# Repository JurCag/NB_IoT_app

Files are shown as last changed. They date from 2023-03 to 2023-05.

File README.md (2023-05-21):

# NB-IoT Application

Table of contents:
- [Introduction](#introduction)
- [System Architecture](#system-architecture)
- [Web Application](#web-application)
- [Firmware and Hardware](#firmware-and-hardware)
    - [Communication overview](#communication-overview)
    - [Development tools](#development-tools)
  - [NB-IoT Concentrator](#nb-iot-concentrator)
    - [Firmware](#firmware)
    - [Hardware](#hardware)
  - [Sensor Boards](#sensor-boards)
    - [Firmware](#firmware)
    - [Hardware](#hardware)
 
#### Introduction:
Project showcases the application of NB-IoT technology for uploading data to the cloud. 
Hardware involves an NB-IoT concentrator and 6 sensor nodes equipped with different sensors, specifically designed to measure parameters of a [photobioreactor](https://en.wikipedia.org/wiki/Photobioreactor).<br />
Simple concept of the application including PBR is available [here](https://github.com/JurCag/NB_IoT_app/blob/master/images/photobioreactor.svg).

#### System Architecture:
<div align="center">
System Architecture
</div>

## Web Application

#### Description:
Simple web application for sensor data visualization and control of NB-IoT concentrator.

#### External libraries:
- AWS SDK: to access AWS services
- JSZip: to manipulate ZIP files
- Highcharts: data visualization

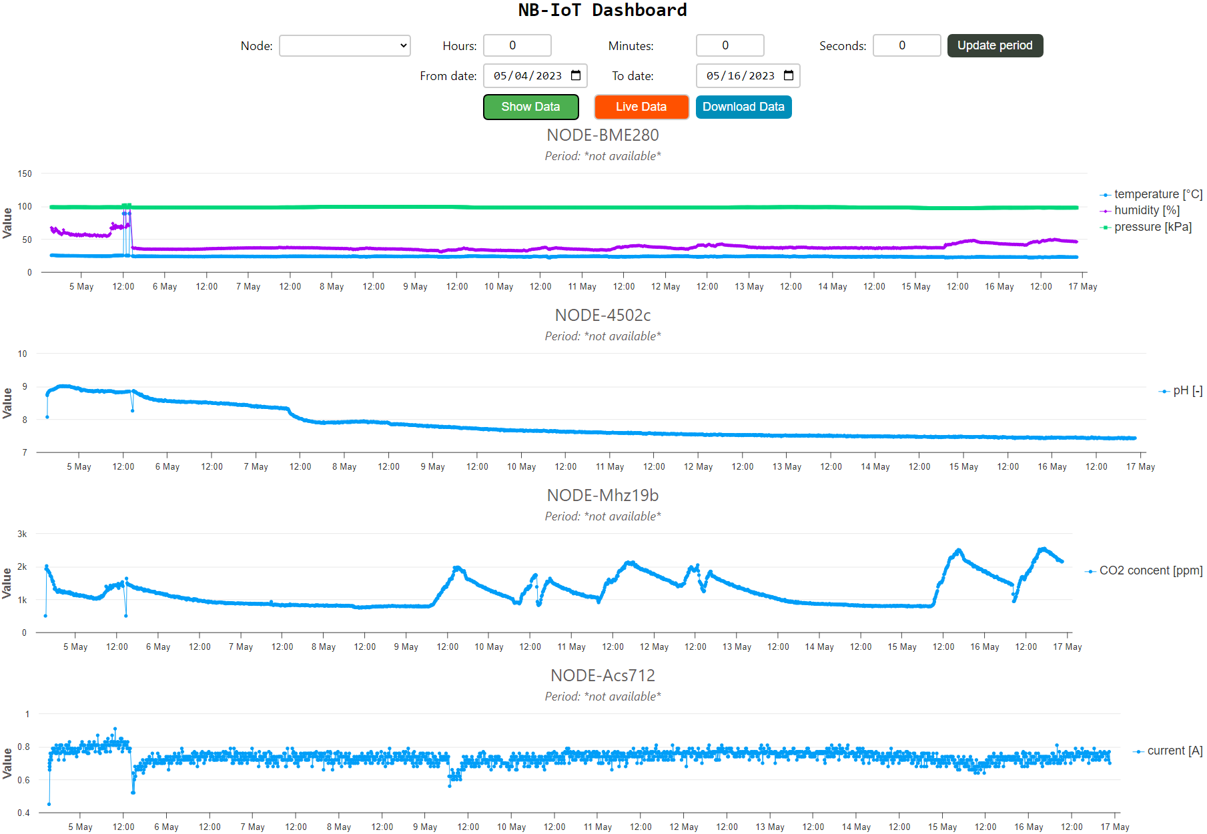
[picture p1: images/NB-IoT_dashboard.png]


## Firmware and Hardware

#### Communication overview:
The application uses [MQTT](https://mqtt.org/) protocol to communicate with broker within the AWS IoT Core. MQTT topics and structure of JSON payloads sent in the messages is shown below.
1) The concentrator provisions new nodes into the BLE mesh network. Nodes provide their descriptors.
2) The user requests the node measurement period by publishing a message to the topic: **BG96_demoThing/mmtPeriods/command**.
3) The concentrator responds with the current measurement period of that node to the topic: **BG96_demoThing/mmtPeriods/response**.
4) The user can change the node measurement period (e.g. 10 minutes).
5) The concentrator confirms the change by repeating the message.
6) The concentrator stores the measurement period value into the NVS (Non-Volatile Storage) memory.
7) When the counter reaches the specified period, the concentrator requests data from the sensor node over the BLE mesh.
8) The sensor node sends measured data.
9) The concentrator uploads the sensory data to AWS on the MQTT topic: **BG96_demoThing/sensors/\<nodeName\>**.
  
<div align="center">
  System Architecture
</div>

#### Development tools:
- VSCode + [PlatformIO](https://platformio.org/)
- Framework: ESP-IDF (within platformio project, no need to install separately)

### NB-IoT Concentrator 
#### Firmware:
- The concentrator, acting as a master device, collects measurement data from sensor nodes and uploads it to the AWS IoT Core.
- The concentrator also establishes a local BLE mesh network and provisions other nodes into the network.
- BLE mesh models implemented by concentrator:
  - Configuration Server
  - Configuration Client
  - Sensor Client 

#### Hardware:
[Custom PCB board](https://github.com/JurCag/NB_IoT_app/tree/master/NB-IoT_PCB_rev_1_1) with ESP32-C3 controller and Quectel BG96 module.

| Component | Link  |
| :---  |:---:|
| **MCU** | [ESP32-C3](https://www.espressif.com/en/products/socs/esp32-c3) |
| **NB-IoT module** | [Quectel BG96](https://www.quectel.com/product/lpwa-bg96-cat-m1-nb1-egprs) |
| **NB-IoT module board** | [LTE IoT 2 Click](https://www.mikroe.com/lte-iot-2-click) |
| **NB-IoT concentrator** | [NB-IoT_PCB_rev_1_1](https://github.com/JurCag/NB_IoT_app/tree/master/NB-IoT_PCB_rev_1_1) |

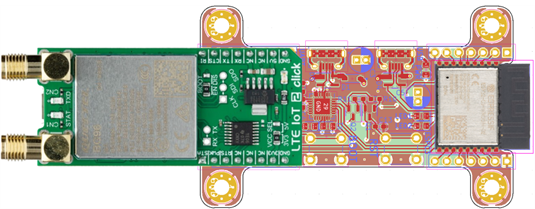
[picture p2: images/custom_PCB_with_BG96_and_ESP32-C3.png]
System Architecture


### Sensor boards
#### Firmware:
- Each sensor node incorporates the same BLE mesh models.
- BLE mesh models implemented by sensor nodes:
  - Configuration Server
  - Sensor Server 
  - Sensor Setup Server 
- The drivers are specific to the corresponding sensor they are equipped with.

#### Hardware:
 - **Control board:<br />**
 Each sensor node has the same control board: [ESP32-C3-DevKitC-02](https://docs.espressif.com/projects/esp-idf/en/latest/esp32c3/hw-reference/esp32c3/user-guide-devkitc-02.html)



 - **Sensors:<br />**

| Physical quantities | Sensor |  Connection | 
| :---: |:---:|:---:|
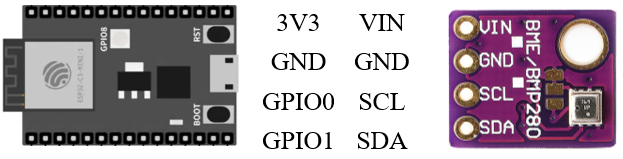
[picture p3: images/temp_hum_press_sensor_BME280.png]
| temperature,<br /> humidity,<br /> pressure | BME280 ||
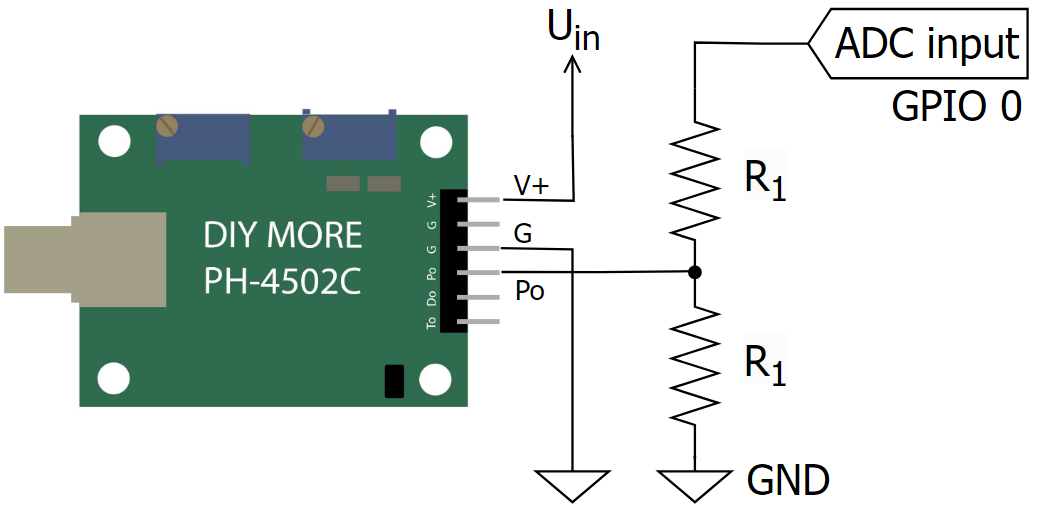
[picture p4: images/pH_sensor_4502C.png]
| pH | PH4502C ||
| CO_2 concentration | MHZ19B ||
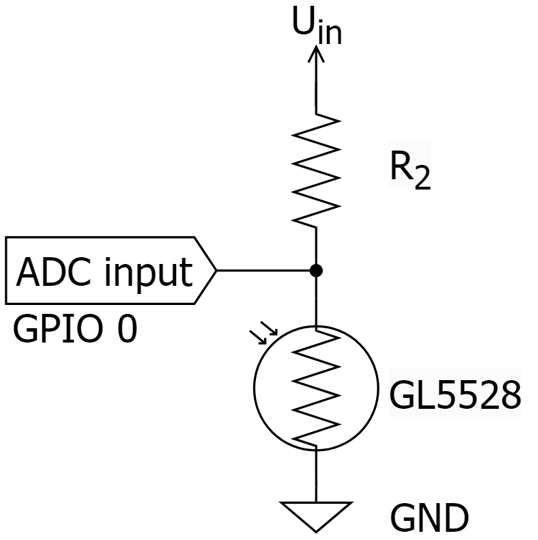
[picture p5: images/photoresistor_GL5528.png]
| light intensity | GL5528 ||
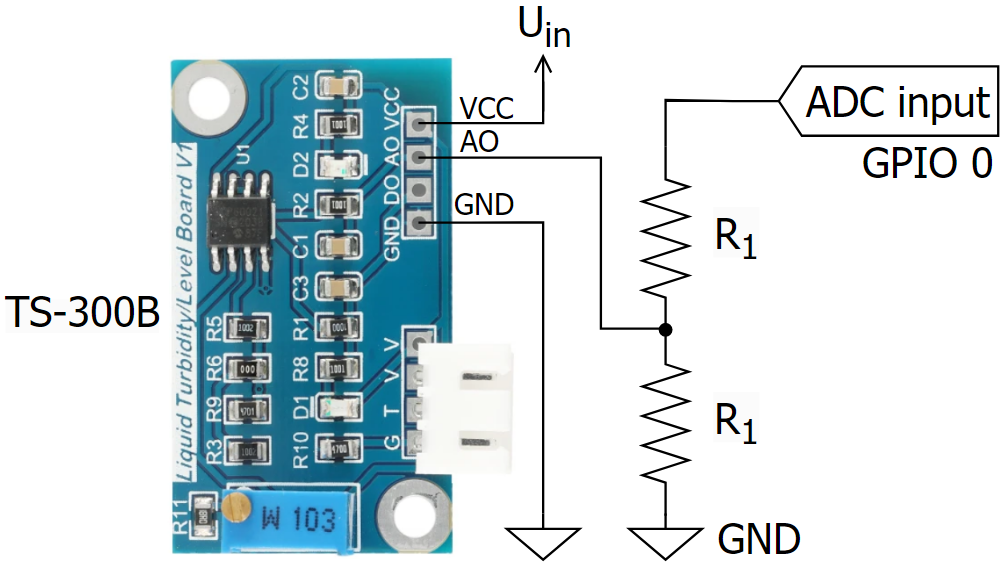
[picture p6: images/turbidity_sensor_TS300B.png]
| turbidity | TS300B ||
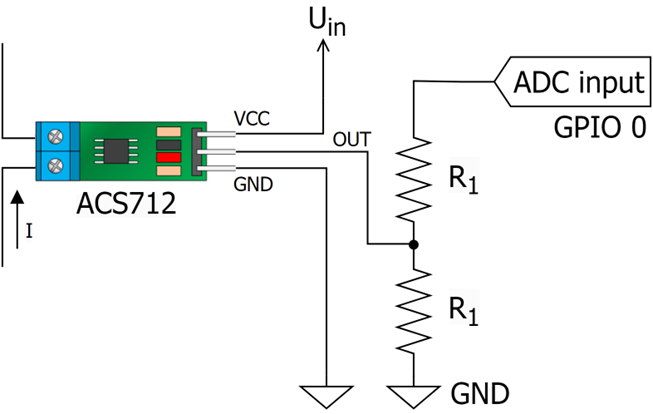
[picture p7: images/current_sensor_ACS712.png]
| electric current | ACS712 ||

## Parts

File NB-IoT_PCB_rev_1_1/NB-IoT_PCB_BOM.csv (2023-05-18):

Id | Designator | Package | Quantity | Designation | Supplier and ref
1 | D3 | D_MiniMELF | 1 | BZV55C15 | https://www.tme.eu/cz/details/bzv55c15-cdi/zenerovy-diody-smd/cdil/bzv55c15/
2 | D4,D5 | SOT-143_Handsoldering | 2 | PRTR5V0U2X | https://www.tme.eu/cz/sk/details/prtr5v0u2x.215/bezpecnostne-diody-rebriky/nexperia/
3 | J2 | USB_Micro-B_Amphenol_10118194_Horizontal | 1 | USB_UART | https://cz.mouser.com/ProductDetail/Hirose-Connector/ZX62D-B-5PA830?qs=1Nn7v2rJFSJs6IftS%252BmZAw%3D%3D
4 | C5,C3 | CP_Radial_D5.0mm_P2.00mm | 2 | 100uF/10V
5 | LED2 | D_0805_2012Metric_Pad1.15x1.40mm_HandSolder | 1 | USER LED 2
6 | D8 | D_0805_2012Metric_Pad1.15x1.40mm_HandSolder | 1 | PWR LED
7 | Q1,Q2 | SOT-23 | 2 | BC817
8 | R11,R10,R9 | R_0603_1608Metric_Pad0.98x0.95mm_HandSolder | 3 | 10k(1%)
9 | J3,J6 | PinSocket_1x08_P2.54mm_Vertical | 2 | Conn_01x08_Female
10 | D7 | D_0805_2012Metric_Pad1.15x1.40mm_HandSolder | 1 | RX LED
11 | C13,C14,C2,C8,C10,C11 | C_0603_1608Metric_Pad1.08x0.95mm_HandSolder | 6 | 100nF/50V
12 | R12,R8,R3,R7 | R_0603_1608Metric_Pad0.98x0.95mm_HandSolder | 4 | 1k
13 | U1 | QFN-28-1EP_5x5mm_P0.5mm_EP3.35x3.35mm | 1 | CP2102N-Axx-xQFN28
14 | LED1 | D_0805_2012Metric_Pad1.15x1.40mm_HandSolder | 1 | USER LED 1
15 | J4,J5 | PinSocket_1x05_P2.54mm_Vertical | 2 | Conn_01x05
16 | R1 | R_0603_1608Metric_Pad0.98x0.95mm_HandSolder | 1 | 22.1k
17 | D6 | D_0805_2012Metric_Pad1.15x1.40mm_HandSolder | 1 | TX LED
18 | D1,D2 | SOD3715X145N | 2 | 1N5819HW | https://www.tme.eu/cz/sk/details/1n5819hw-7-f/diody-schottky-smd/diodes-incorporated/
19 | RST1,BOOT1 | SW_PUSH_6mm_H5mm | 2 | SW_Push
20 | U3 | ESP32-C3-WROOM-02 | 1 | ESP32-C3-WROOM-02
21 | C4 | C_0603_1608Metric_Pad1.08x0.95mm_HandSolder | 1 | 1uF/50V
22 | J1 | USB_Micro-B_Amphenol_10118194_Horizontal | 1 | USB | https://cz.mouser.com/ProductDetail/Hirose-Connector/ZX62D-B-5PA830?qs=1Nn7v2rJFSJs6IftS%252BmZAw%3D%3D
23 | R2 | R_0603_1608Metric_Pad0.98x0.95mm_HandSolder | 1 | 47.5k
24 | U2 | SOT-223-3_TabPin2 | 1 | LD1117S33TR_SOT223 | https://www.tme.eu/cz/details/ld1117s33ctr/stabilizatory-napeti-neregulovane-ldo/stmicroelectronics/
25 | F1 | FP_for_SD050-16_POLY_FUSE | 1 | SD050-16_Poly_Fuse | http://www.tme.eu/cz/details/sd050-16/polymerove-pojistky-smd/ece/
26 | R5,R4 | R_0603_1608Metric_Pad0.98x0.95mm_HandSolder | 2 | 0(1%)
27 | R13,R14 | R_0603_1608Metric_Pad0.98x0.95mm_HandSolder | 2 | 1k(NC)
28 | C9 | C_1206_3216Metric_Pad1.33x1.80mm_HandSolder | 1 | 10uF/50V
29 | R6 | R_0603_1608Metric_Pad0.98x0.95mm_HandSolder | 1 | 0(1%)(NC)
30 | C6 | C_1206_3216Metric_Pad1.33x1.80mm_HandSolder | 1 | 1uF/50V
31 | C1 | C_1210_3225Metric_Pad1.33x2.70mm_HandSolder | 1 | 4.7uF
32 | C12,C7 | C_0805_2012Metric_Pad1.18x1.45mm_HandSolder | 2 | 10uF/50V

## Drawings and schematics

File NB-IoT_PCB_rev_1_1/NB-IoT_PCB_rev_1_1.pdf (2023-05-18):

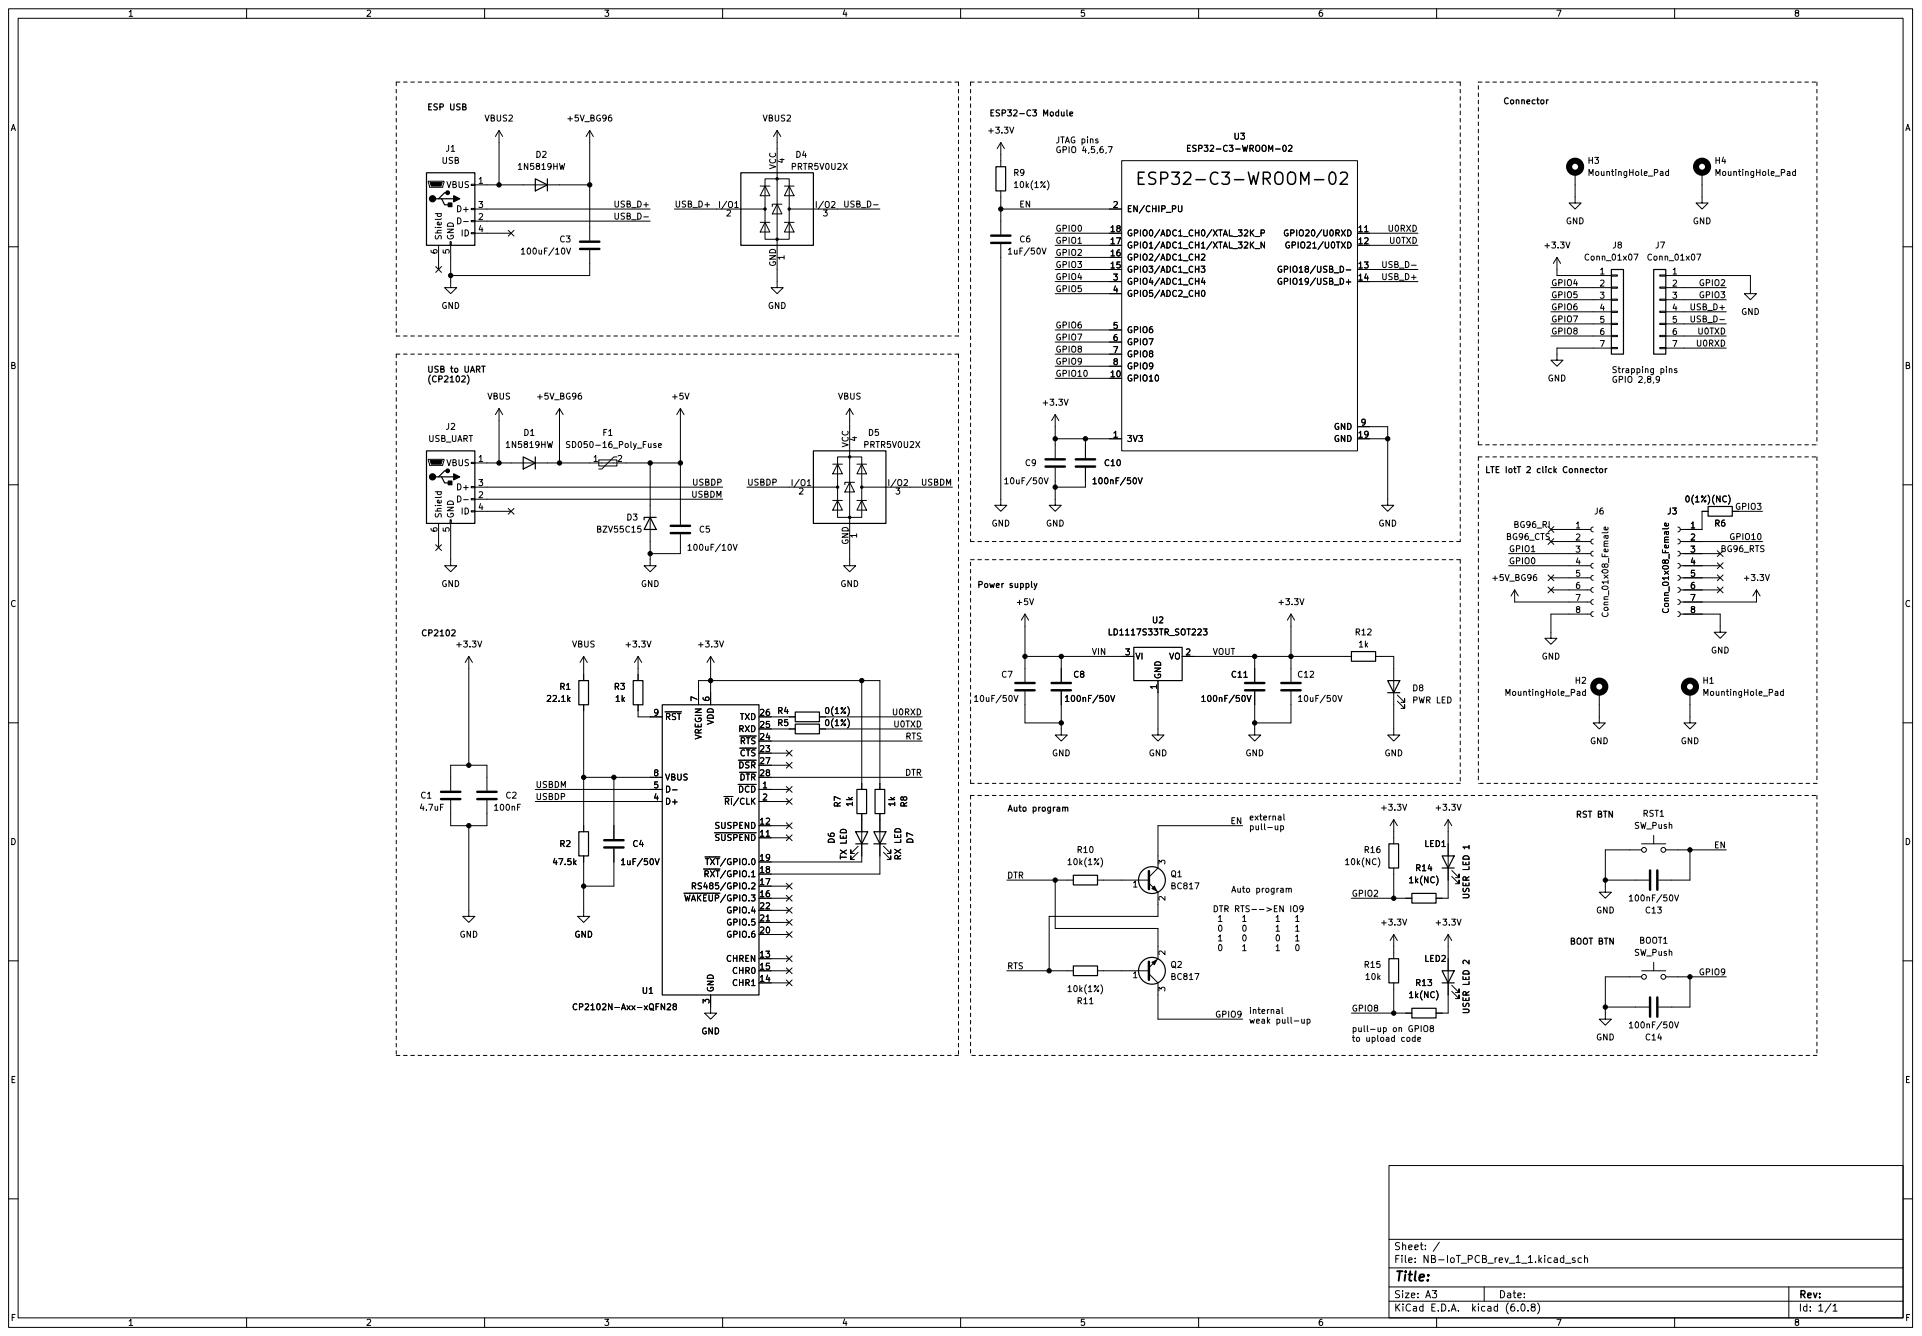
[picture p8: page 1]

JTAG pins GPIO 4,5,6,7 ESP32-C3 Module

internal weak pull-up

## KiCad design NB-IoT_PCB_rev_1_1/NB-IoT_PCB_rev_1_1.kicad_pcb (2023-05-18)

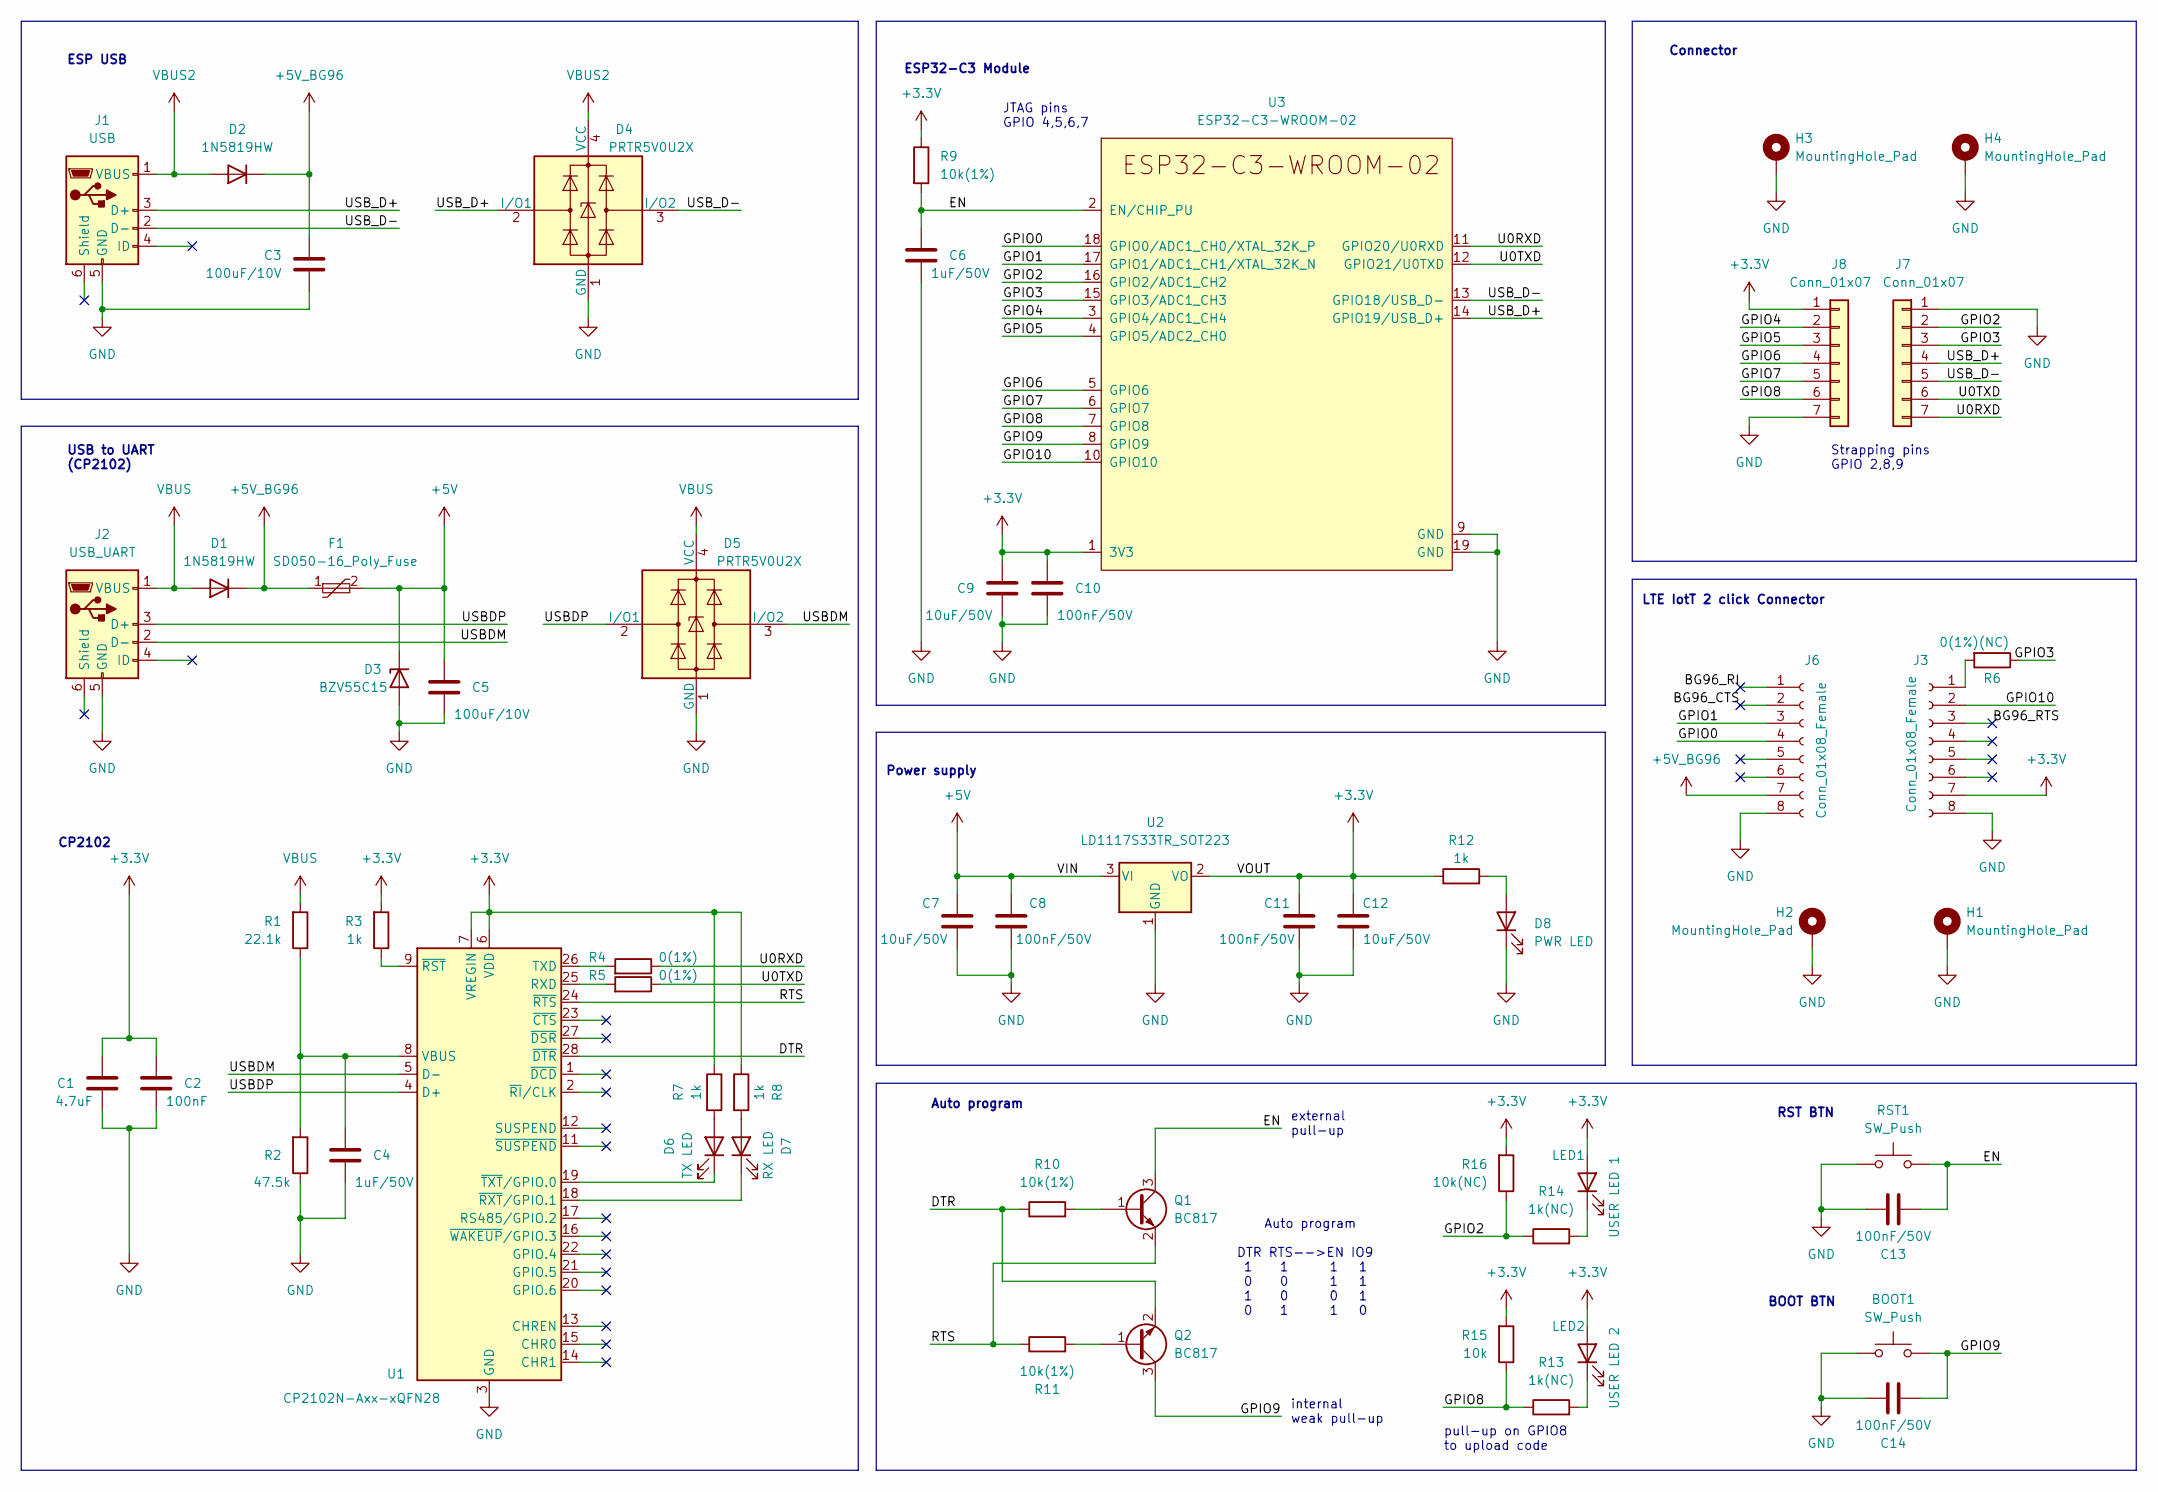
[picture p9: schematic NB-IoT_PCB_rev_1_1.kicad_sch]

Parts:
BOOT1: SW_Push; SW_PUSH_6mm_H5mm
C1: 4.7uF; C_1210_3225Metric_Pad1.33x2.70mm_HandSolder
C2: 100nF; C_0603_1608Metric_Pad1.08x0.95mm_HandSolder
C3, C5: 100uF/10V; CP_Radial_D5.0mm_P2.00mm
C4, C6: 1uF/50V; C_0603_1608Metric_Pad1.08x0.95mm_HandSolder
C7, C12: 10uF/50V; C_0805_2012Metric_Pad1.18x1.45mm_HandSolder
C8, C10, C11, C13, C14: 100nF/50V; C_0603_1608Metric_Pad1.08x0.95mm_HandSolder
C9: 10uF/50V; C_1206_3216Metric_Pad1.33x1.80mm_HandSolder
D1, D2: 1N5819HW; SOD3715X145N
D3: BZV55C15; D_MiniMELF
D4, D5: PRTR5V0U2X; SOT-143_Handsoldering
D6: TX LED; D_0805_2012Metric_Pad1.15x1.40mm_HandSolder
D7: RX LED; D_0805_2012Metric_Pad1.15x1.40mm_HandSolder
D8: PWR LED; D_0805_2012Metric_Pad1.15x1.40mm_HandSolder
F1: SD050-16_Poly_Fuse; FP_for_SD050-16_POLY_FUSE
H1, H2, H3, H4: MountingHole_Pad; MountingHole_3.2mm_M3_Pad_Via
J1: USB; USB_Micro-B_Amphenol_10118194_Horizontal
J2: USB_UART; USB_Micro-B_Amphenol_10118194_Horizontal
J3, J6: Conn_01x08_Female; PinSocket_1x08_P2.54mm_Vertical
J7, J8: Conn_01x07; PinSocket_1x07_P2.54mm_Vertical
LED1: USER LED 1; D_0805_2012Metric_Pad1.15x1.40mm_HandSolder
LED2: USER LED 2; D_0805_2012Metric_Pad1.15x1.40mm_HandSolder
Q1, Q2: BC817; SOT-23
R1: 22.1k; R_0603_1608Metric_Pad0.98x0.95mm_HandSolder
R2: 47.5k; R_0603_1608Metric_Pad0.98x0.95mm_HandSolder
R3, R7, R8, R12: 1k; R_0603_1608Metric_Pad0.98x0.95mm_HandSolder
R4, R5: 0(1%); R_0603_1608Metric_Pad0.98x0.95mm_HandSolder
R6: 0(1%)(NC); R_0603_1608Metric_Pad0.98x0.95mm_HandSolder
R9, R10, R11: 10k(1%); R_0603_1608Metric_Pad0.98x0.95mm_HandSolder
R13, R14: 1k(NC); R_0603_1608Metric_Pad0.98x0.95mm_HandSolder
R15: 10k; R_0603_1608Metric_Pad0.98x0.95mm_HandSolder
R16: 10k(NC); R_0603_1608Metric_Pad0.98x0.95mm_HandSolder
RST1: SW_Push; SW_PUSH_6mm_H5mm
U1: CP2102N-Axx-xQFN28; QFN-28-1EP_5x5mm_P0.5mm_EP3.35x3.35mm
U2: LD1117S33TR_SOT223; SOT-223-3_TabPin2
U3: ESP32-C3-WROOM-02

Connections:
+3.3V: C1.2, C2.2, C9.2, C10.1, C11.1, C12.1, J3.7, J8.1, LED1.2 (A), LED2.2 (A), R3.2, R7.1, R8.1, R9.1, R12.1, R15.2, R16.2, U1.6 (VDD), U1.7 (VREGIN), U2.2 (VO), U3.1 (3V3)
+5V: C5.1, C7.1, C8.1, D3.1 (K), F1.2, U2.3 (VI)
+5V_BG96: C3.1, D1.2 (K), D2.2 (K), F1.1, J6.7
/BG96_CTS: J6.2
/BG96_RI: J6.1
/BG96_RTS: J3.3
/DTR: Q2.2 (E), R10.1, U1.28 (~DTR)
/EN: C6.1, C13.2, Q1.3 (C), R9.2, RST1.2, U3.2 (EN/CHIP_PU)
/GPIO0: J6.4, U3.18 (GPIO0/ADC1_CH0/XTAL_32K_P)
/GPIO1: J6.3, U3.17 (GPIO1/ADC1_CH1/XTAL_32K_N)
/GPIO2: J7.2, R14.1, R16.1, U3.16 (GPIO2/ADC1_CH2)
/GPIO3: J7.3, R6.1, U3.15 (GPIO3/ADC1_CH3)
/GPIO4: J8.2, U3.3 (GPIO4/ADC1_CH4)
/GPIO5: J8.3, U3.4 (GPIO5/ADC2_CH0)
/GPIO6: J8.4, U3.5 (GPIO6)
/GPIO7: J8.5, U3.6 (GPIO7)
/GPIO8: J8.6, R13.1, R15.1, U3.7 (GPIO8)
/GPIO9: BOOT1.2, C14.2, Q2.3 (C), U3.8 (GPIO9)
/GPIO10: J3.2, U3.10 (GPIO10)
/RTS: Q1.2 (E), R11.1, U1.24 (~RTS)
/U0RXD: J7.7, R4.1, U3.11 (GPIO20/U0RXD)
/U0TXD: J7.6, R5.1, U3.12 (GPIO21/U0TXD)
/USBDM: D5.3 (I/O2), J2.2 (D-), U1.5 (D-)
/USBDP: D5.2 (I/O1), J2.3 (D+), U1.4 (D+)
/USB_D+: D4.2 (I/O1), J1.3 (D+), J7.4, U3.14 (GPIO19/USB_D+)
/USB_D-: D4.3 (I/O2), J1.2 (D-), J7.5, U3.13 (GPIO18/USB_D-)
GND: BOOT1.1, C1.1, C2.1, C3.2, C4.1, C5.2, C6.2, C7.2, C8.2, C9.1, C10.2, C11.2, C12.2, C13.1, C14.1, D3.2 (A), D4.1 (GND), D5.1 (GND), D8.1 (K), H1.1, H2.1, H3.1, H4.1, J1.5 (GND), J2.5 (GND), J3.8, J6.8, J7.1, J8.7, R2.1, RST1.1, U1.3 (GND), U1.29 (GND), U2.1 (GND), U3.9 (GND), U3.19 (GND)
unnamed: C4.2, R1.1, R2.2, U1.8 (VBUS)
unnamed: D6.1 (K), U1.19 (~TXT/GPIO.0)
unnamed: D6.2 (A), R7.2
unnamed: D7.1 (K), U1.18 (~RXT/GPIO.1)
unnamed: D7.2 (A), R8.2
unnamed: D8.2 (A), R12.2
unnamed: J3.1, R6.2
unnamed: LED1.1 (K), R14.2
unnamed: Q1.1 (B), R10.2
unnamed: Q2.1 (B), R11.2
unnamed: R3.1, U1.9 (~RST)
unnamed: R4.2, U1.26 (TXD)
unnamed: R5.2, U1.25 (RXD)
unnamed: LED2.1 (K), R13.2
VBUS: D1.1 (A), D5.4 (VCC), J2.1 (VBUS), R1.2
VBUS2: D2.1 (A), D4.4 (VCC), J1.1 (VBUS)

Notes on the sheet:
CP2102
Strapping pins GPIO 2,8,9
Power supply
Auto program DTR RTS-->EN IO9 1 1 1 1 0 0 1 1 1 0 0 1 0 1 1 0
internal weak pull-up
Auto program
Connector
LTE IotT 2 click Connector
JTAG pins GPIO 4,5,6,7
USB to UART (CP2102)
ESP USB
ESP32-C3 Module
pull-up on GPIO8 to upload code
external pull-up
RST BTN
BOOT BTN

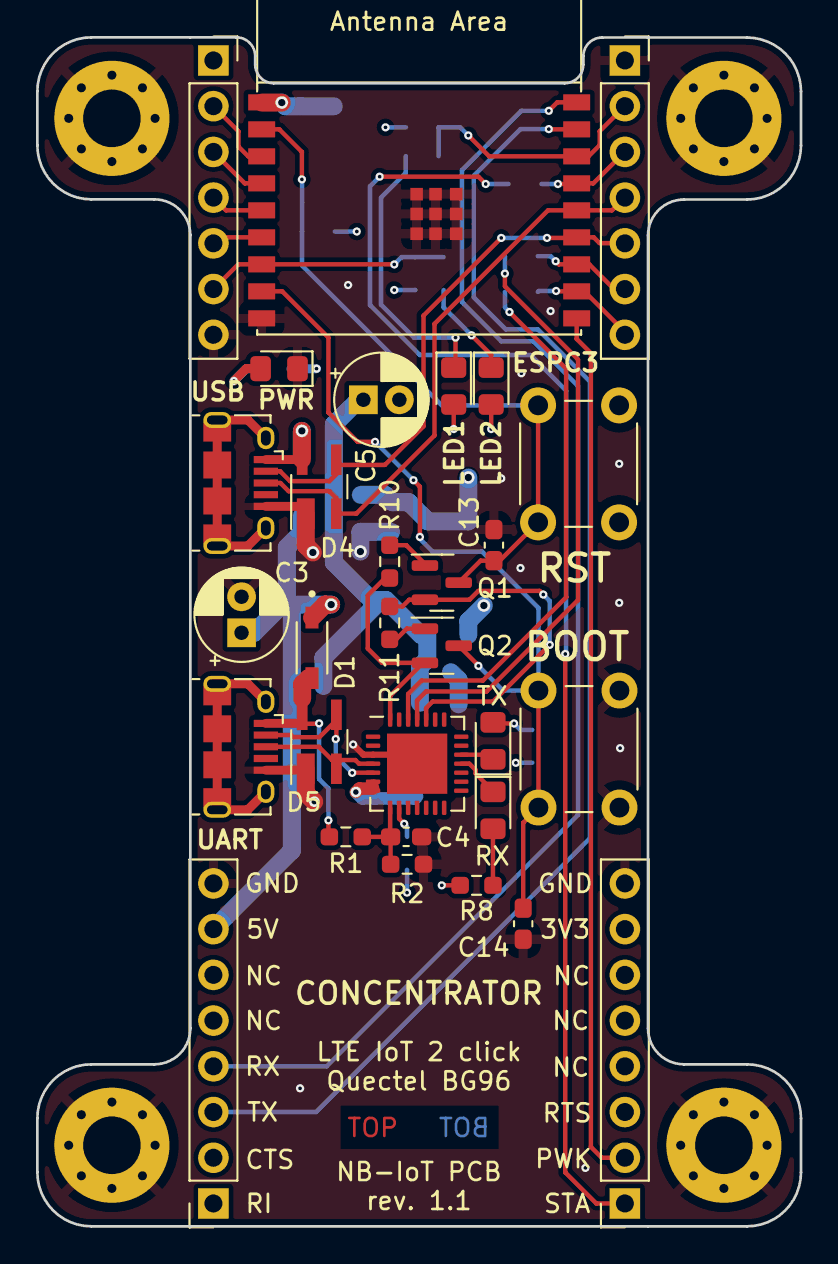
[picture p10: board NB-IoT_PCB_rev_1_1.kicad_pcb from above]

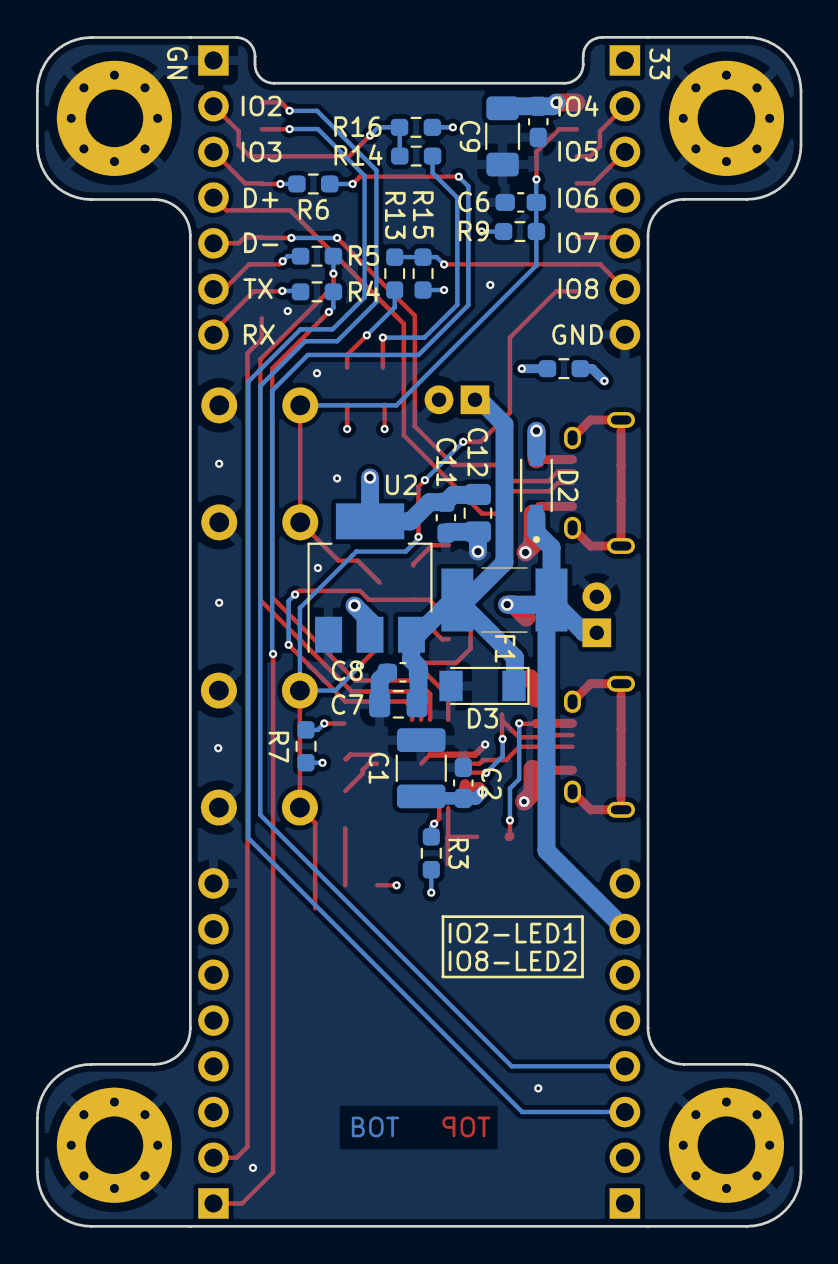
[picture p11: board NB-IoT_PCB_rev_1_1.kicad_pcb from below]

Board: 4 copper layers, 42.4 x 66.1 mm, 58 parts (24 on the bottom side), 40 nets.

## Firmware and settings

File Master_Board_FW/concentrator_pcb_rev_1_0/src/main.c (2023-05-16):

#include "main.h"

void app_main() 
{
    /* IO */
    initIO();
    gpio_set_level(USER_LED_1, 0);
    
    /* UART with PC */
    UART_initConfig(UART_PC);
    UART_initIO(UART_PC, UART_PC_TX_PIN, UART_PC_RX_PIN);
    UART_installDriver(UART_PC);

    /* UART with GSM modem */
    UART_initConfig(UART_BG96);
    UART_initIO(UART_BG96, UART_BG96_TX_PIN, UART_BG96_RX_PIN);
    UART_installDriver(UART_BG96);

    char str[64];
    sprintf(str, "\r\nConfig FreeRTOS freq = [%d] Hz\r\n", CONFIG_FREERTOS_HZ);
    UART_writeStr(UART_PC, str);
    TASK_DELAY_MS(2000);

    if(CONFIG_FREERTOS_HZ == DESIRED_FREERTOS_FREQ)
    {
        /* BLE Mesh */
        esp_log_level_set("*", ESP_LOG_INFO);
        nbiotReceivedSensorDataRegisterCB(nbiotSensorDataToBg96);
        BG96_registerStartGatheringSensorDataCB(nbiotCreateTaskSensorDataGathering);
        nbiotBleMeshAppMain();

        /* Initialize FreeRTOS components */
        createRxDataQueue();
        createAtPacketsTxQueues();

        TASK_DELAY_MS(1000);

        /* Create FreeRTOS tasks */
        createTaskRx();
        createTaskPowerUpModem(PWRKEY_PIN);
    }
    else
    {
        sprintf(str, "\r\n[PROBLEM] Set CONFIG_FREERTOS_HZ = [%d] Hz in menuconfig\r\n", 
                DESIRED_FREERTOS_FREQ);
        UART_writeStr(UART_PC, str);
    }
}

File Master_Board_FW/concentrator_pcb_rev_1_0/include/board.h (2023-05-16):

#ifndef __BOARD_H__
#define __BOARD_H__
/* board.h specifies board related pins, peripherals, ... */

#include <driver/gpio.h>
#include <driver/uart.h>
#include <soc/soc.h>

#define PWRKEY_PIN          (GPIO_NUM_10)
#define USER_LED_1          (GPIO_NUM_2)
#define USER_LED_2          (GPIO_NUM_8)

#define UART_BG96           (UART_NUM_1)
#define UART_BG96_TX_PIN    (GPIO_NUM_0)
#define UART_BG96_RX_PIN    (GPIO_NUM_1)

#define UART_PC             (UART_NUM_0)
#define UART_PC_TX_PIN      (GPIO_NUM_5)
#define UART_PC_RX_PIN      (GPIO_NUM_4)

void initIO(void);
void setPwrKeyHigh(void);
void setPwrKeyLow(void);

#endif // __BOARD_H__

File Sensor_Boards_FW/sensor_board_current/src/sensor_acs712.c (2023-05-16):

#include "sensor_acs712.h"

static void taskDataAcq(void *pvParameters);
static uint32_t mV;
static uint32_t rawVal;

static uint32_t mvSum;
static uint32_t mvAvg;
static uint8_t cnt = 0;

void sensorAcs712CreateTaskDataAcq(void)
{
    xTaskCreate(
                taskDataAcq,           			/* Task function */
                "taskDataAcq",         			/* Name of task */
                2048,                           /* Stack size of task */
                NULL,                           /* Parameter of the task */
                tskIDLE_PRIORITY + 0,           /* Priority of the task */
                NULL                   			/* Handle of created task */
                );
}

static void taskDataAcq(void *pvParameters)
{
    if (adcConfig() == EXIT_SUCCESS)
    {
        while(1)
        {
            vTaskDelay(25/portTICK_PERIOD_MS);
            
            mV = adcGetVoltage();
            rawVal = adcGetRawValue();

            cnt++;
            mvSum += mV;
            if (cnt % 40 == 0)
            {
                mvAvg = mvSum / cnt;
                printf("Voltage: %d mV, raw value: %d, current: %.2f A\n", mvAvg, rawVal, sensorAcs712GetCurrent());
                cnt = 0;
                mvSum = 0;
            }
        }
    }

    ESP_LOGE(TAG_PHOTORES, "Failed to configure ADC.");
    ESP_LOGE(TAG_PHOTORES, "TASK DELETING ITSELF");
	vTaskDelete(NULL);
}

float sensorAcs712GetCurrent(void)
{
    static float theoreticalVal;
    static float linCalibratedVal;
    theoreticalVal = (((float)mvAvg / VOLTAGE_DIVIDER_RATIO) - ACS712_0A_OUTPUT_VOLTAGE) / ACS712_SENSITIVITY;
    linCalibratedVal = (1.0 / LIN_CALIB_GAIN) * (theoreticalVal - LIN_CALIB_OFFSET);
    return linCalibratedVal;
    // return ((((float)mvAvg) * 0.02074f) - 24.27);
}

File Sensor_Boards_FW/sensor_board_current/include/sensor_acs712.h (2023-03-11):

#ifndef __SENSOR_ACS712_H__
#define __SENSOR_ACS712_H__

#include "adc.h"
#include "esp_err.h"
#include "esp_log.h"
#include "freertos/FreeRTOS.h"
#include "freertos/task.h"

#define TAG_PHOTORES ("ACS712")

// Sensitivity from datasheet (mV/A)
#define ACS712_SENSITIVITY              (100.0)

// Sensor output voltage (mV) at 0A current
#define ACS712_0A_OUTPUT_VOLTAGE        (2307.0)

// Voltage divieder R1 = 100k, R2 = 100k
// ADC voltage measured on R2 -> ratio = R2/(R1 + R2)
#define VOLTAGE_DIVIDER_RATIO           (1.0/2.0)

// Manual callibration (linear, y = a * x + b)
// y ... real (measured/known) current
// x ... uncallibrated current (from ESP)
// a ... linear gain
// b ... linear offset
#define LIN_CALIB_GAIN                  (1.037)
#define LIN_CALIB_OFFSET                (0.34641)

void sensorAcs712CreateTaskDataAcq(void);
float sensorAcs712GetCurrent(void);

#endif // __SENSOR_ACS712_H__

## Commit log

2022-12-11 Add env:c3_debug to debug ESP through built-in JTAG interface. (also change PC uart pins)
2022-12-13 Create new sensor board project for BME280 (temperature, humidity, pressure)
2022-12-18 [1] Implement BLE mesh Sensor Server from ESP-IDF sensor_server example, and modify it so it sends measured data from the sensor using callback. [2] Implement reading of measurement data from BME280 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
    [partitions.csv]
2023-01-03 [1] Implement BLE mesh provisioner & sensor client from ESP-IDF sensor_client example with modifications to forward gathered sensor data. [2] Implement interface which connects BLE mesh and BG96 part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
    [partitions.csv]
2023-01-04 [1] Add timeoutCnt to NbiotBleMeshNode_t and functions to keep track of how many times each node times out. [2] Edit tracking of node being provisioned to be tracked from the moment provisioner recei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
    [main.c]
2023-01-04 Create new project for concentrator board pcb rev 1.0 based on breadboard_demo. Yet no modifications.
    [partitions.csv]
2023-01-06 Modify descriptor to custom nbiotSensorServerDescriptor_t which adds to original descriptor new data specified in struct NbiotSensorSetup_t. Implement it on both, provisioner and sensor server sides.
2023-01-08 Pack BLE mesh server functionality into 'server_include' and 'server_src' folders. Specific sensor server nodes should be build on top of it.
2023-01-08 [1] Extend the NbiotSensorSetup_t by measurement unit. [2] Provisioner now waits to start gathering sensor data after the GSM connection is established. (Still leave an option to gather data even if 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
2023-01-08 Create new sensor board project for photoresistor (light intensity).
    [partitions.csv]
2023-01-11 FW for NB-IoT PCB rev 1.0. Both GSM and BLE Mesh components tested. FW is just modified breadboard demo but no significant changes.
2023-01-13 [1] Change structure of json data being send to AWS. Whole data of one node is within one mqtt packet.[2] Fix uartRx task to build incoming data even if longer than UART THRESHOLD.
2023-01-15 Create new sensor board project for ACS712 (dc current sensor).
    [partitions.csv]
2023-01-23 Create new sensor board project for MHZ19B (CO2 concentration sensor).
    [partitions.csv]
2023-01-28 ESP <--> BG96 AT communication redesign. taskAtPacketTxScheduler manages AT packets to be sent to taskTx while packets are still being queued by queueAtPacket function, which can be called from anywh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
    [main.c]
2023-01-28 Redesign the BG96_atCmdFamilyParser and BG96_mqttResponseParser to be able to resend the same payload in case when AT cmd was successfully sent to BG96, but the mqtt publish failed.
2023-01-29 Create new sensor board project for TS-300B (turbidity).
    [partitions.csv]
2023-01-31 Create new sensor board project for 4502C (pH of liquids).
    [partitions.csv]
2023-01-31 Update size of NET_BUF_SIMPLE_DEFINE_STATIC across sensor projects.
2023-02-12 Create simple sensor measurements dashboard for Amazon S3 buckets.
2023-03-08 Add functionality to ask concentrator for nodes mmt period whenever switched to live mode.
2023-03-11 Calibrate conversion from mV to current.
2023-03-12 [1] Add functionality to query individual nodes mmt period (for the web app). [2] Option to name nodes according to their sensor. [3] Functionality to RE-OPEN MQTT connection.
2023-03-12 Change pressure units to kPa
2023-03-14 Change turbidity units and calculation from NTU to dimensionless, since NTU calibration is very hard to achieve.
    [partitions.csv]
2023-03-14 [1] Callibration of pH sensor offset (on pH = 7), but gain not compensated yet. [2] Remove concentrator_pcb_rev_1_1 project, which was added accidentally.
    [partitions.csv]
2023-04-01 Add overhead testing and initial wait procedure when connecting into NB-IoT network.
    [partitions.csv]
2023-05-16 Calibration and minor changes of sensor board projects.
2023-05-16 Minor changes, LED indication and some comments before submission.
2023-05-18 Add KiCad concentrator project.
    [NB-IoT_PCB_BOM.csv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]
